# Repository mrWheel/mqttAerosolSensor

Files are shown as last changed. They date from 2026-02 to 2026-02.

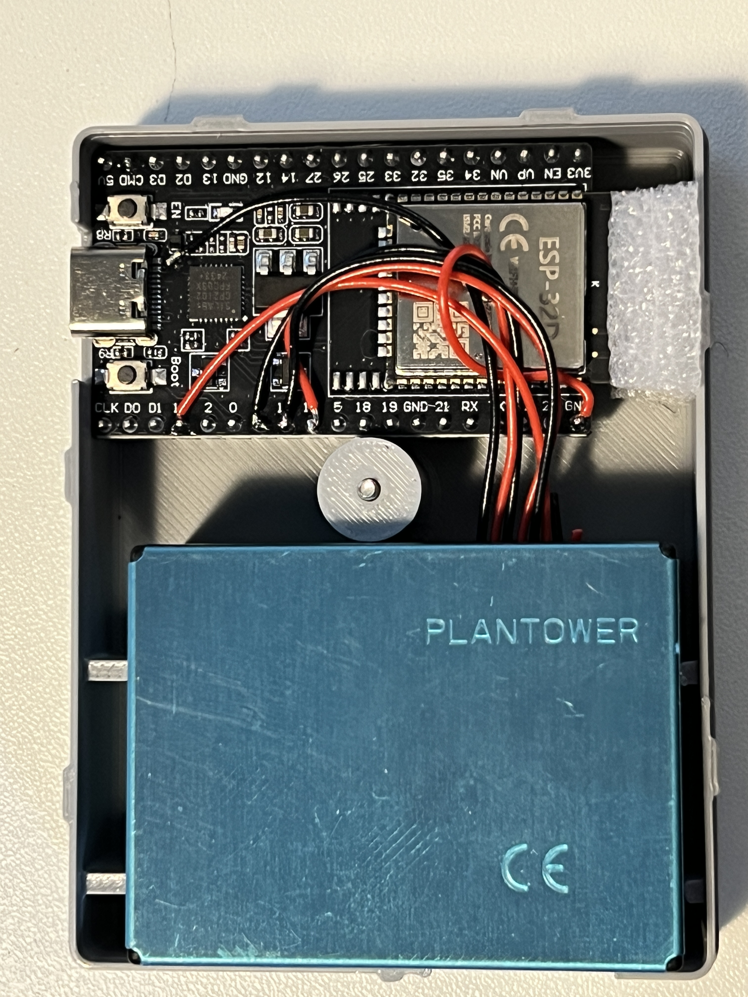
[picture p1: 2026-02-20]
documentation/IMG_9015.JPG

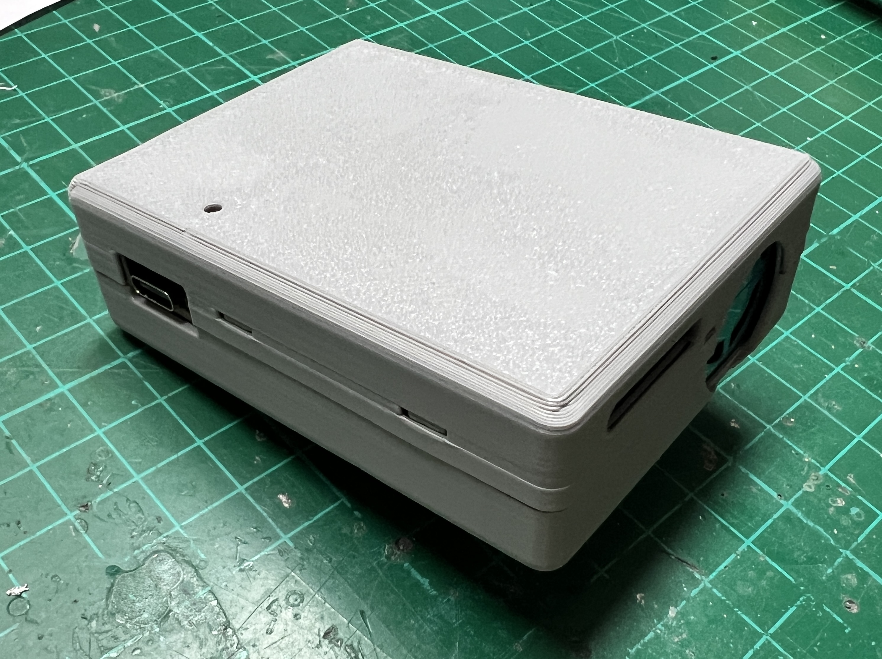
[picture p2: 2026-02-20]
documentation/IMG_9016.jpg

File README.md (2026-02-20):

# luchtSensor

A firmware project for **ESP32 DevKit boards** using **PlatformIO** and the **Arduino framework**.

## Overview

This project manages ESP32 firmware application for a luchtSensor:

### Air Sensor (Luchtsensor)
   - Measures particulate matter using PMSerial sensor
   - Publishes periodic measurements via MQTT
   
Code:
- Use **FreeRTOS** for task management
- Configure WiFi and MQTT via **WiFiManagerExt** captive portal
- Support **JSON** via ArduinoJson
- Feature a button (active within 30s after boot) to clear WiFi credentials
- Implement comprehensive logging via the **Logger** utility

## Architecture

```
┌────────────────────┐
│   MQTT Broker      │
└────────┬───────────┘
         │
         ▼                                        
┌─────────────────────┐  
│   Air Sensor        │  
│  (ESP32-Dev)        │  
│─────────────────────│  
│ WiFiManagerExt      │  
│ MqttClient          │  
│ pms5003AirSensor    |  
|           (PMSerial)│  
│─────────────────────│  
│ Publishes:          │  
│  - luchtsensor/data │  
└─────────────────────┘  
```

## Project Structure

```
luchtSensor/
├── platformio.ini              # PlatformIO configuratie
├── .gitignore                  # Git exclusions
├── DOCUMENTATION.md            # Projectdocumentatie
├── roadmap.md                  # Dit bestand
│
├── include/                    # Gedeelde code
│   ├── pms5003AirSensor.h      # Fijnstofsensor wrapper (PMSerial)
│   ├── logger.h                # Centrale logging utility
│   ├── mqttClient.h            # MQTT client wrapper (PubSubClient)
│   ├── mqttConfig.h            # MQTT configuratie storage
│   └── wifiManagerExt.h        # WiFi/MQTT configuratie manager
│
├── src/                    
│   ├── main.cpp                # Hoofd programma
│   ├── pms5003AirSensor.cpp    # Fijnstofsensor wrapper (PMSerial)
│   ├── logger.cpp              # Centrale logging utility
│   ├── mqttClient.cpp          # MQTT client wrapper (PubSubClient)
│   ├── mqttConfig.cpp          # MQTT configuratie storage
│   └── wifiManagerExt.cpp      # WiFi/MQTT configuratie manager
│
├── documentation/             # Extra documentatie
│   └── mqtt-architecture-diagram.txt
│
├── config_examples/           # Voorbeeld configuraties
│   └── multi_device_mqtt.yaml
│
└── .pio.nosync/              # Build artifacts (niet in git)
```

## Features

### include

#### Logger
Centralized logging utility with:
- Log levels: `INFO`, `WARN`, `ERROR`, `DEBUG`
- Automatic timestamps in milliseconds
- Printf-style formatting
- Consistent output across all modules

```cpp
Logger::info("Device started");
Logger::warn("Low memory");
Logger::error("Sensor read failed");
Logger::debug("Variable x = %d", x);
```

#### WiFiManagerExt
Extended WiFi configuration manager:
- Captive portal for WiFi and MQTT setup
- Stores credentials in LittleFS (`/config.json`)
- **PIN_ERASE_WIFI** monitoring during WiFi connection
- 60-second timeout with automatic restart

#### MqttClient
MQTT client wrapper:
- Simplified publish/subscribe with JSON support
- Automatic reconnection handling
- Built on PubSubClient library

#### Air Sensor
- Measures PM1.0, PM2.5, PM10 concentrations
- Configurable measurement interval (default: 2 minutes)
- Publishes to `pms5003/data` topic
- **PIN_ERASE_WIFI** clears credentials within 20 seconds of boot

## Getting Started

### Prerequisites

- [PlatformIO](https://platformio.org/) installed
- ESP32 DevKit board
- USB cable for programming

### Building

The project uses environment-specific builds. Never build the default environment:

```bash
# Build air sensor firmware
pio run -e mqttAerosolSensor
```

### Uploading

```bash
# Upload air sensor
pio run -e mqttAerosolSensor --target upload
```

### Monitoring

```bash
# Monitor serial output (115200 baud)
pio device monitor -e mqttAerosolSensor
```

## Configuration

### First Boot

On first boot, the device will:
1. if no config.json found ór if there are not allready WiFi-credentiels;
   - Start a WiFi access point (AP mode) 
   - Display AP name on serial output
   - Open configuration portal at `192.168.4.1`

### Configuration Portal

Connect to the device's WiFi AP and navigate to the portal to configure:
- **WiFi SSID and password**
- **MQTT broker host** (IP or hostname)
- **MQTT port** (default: 1883)
- **MQTT topix** (default: pms5003/data)
- **MQTT username** (optional)
- **MQTT password** (optional)

Settings are saved to LittleFS and persist across reboots.

### PIN_ERASE_WIFI

To clear all WiF credentials:
1. Press and release the PIN_ERASE_WIFI button a few times during boot within 30 seconds after boot-start
2. Release button
3. Device will restart in configuration mode

## GPIO Pin Assignments

### Air Sensor

| Pin | Function | Notes |
|-----|---|---|
| GPIO16 | PM Sensor RX | UART receive from sensor |
| GPIO17 | PM Sensor TX | UART transmit to sensor |
| GPIOx | Config Button | Active after 10 seconds pressed |

## MQTT Topics
**Publishes:**
- `pms5003/data` - Measurement data in JSON format

**Example payload:**
```json
{
  "devId": "LS609c3e08",
  "pm1": 7.6,
  "pm25": 8.7,
  "pm10": 12.3,
  "timestamp": 123456
}
```

**Fields:**
- `devId`: Unique device identifier based on MAC address (format: LS + last 8 hex digits of MAC)
- `pm1`: PM1.0 concentration in µg/m³
- `pm25`: PM2.5 concentration in µg/m³
- `pm10`: PM10 concentration in µg/m³
- `timestamp`: Milliseconds since device boot

## FreeRTOS Tasks

| Task | Function |
|---|---|
| taskButtonMonitor | Monitors PIN_ERASE_WIFI |
| taskMqttLoop | Maintains MQTT connection |
| taskMeasurement | Periodic sensor readings |

## Development

### PlatformIO Configuration

The project uses `platformio.ini`:

- **[env]**: Shared configuration
- **[env:mqttAerosolSensor]**: Air sensor specific settings

### Build Flags

Build flags define specific parameters:
- Device identifiers
- GPIO pin assignments
- Timing intervals
- MQTT topics

See `platformio.ini` for complete configuration details.

## Dependencies

### Core Libraries
- **WiFiManager** (^2.0.17) - WiFi configuration portal
- **PubSubClient** - MQTT client
- **ArduinoJson** (^7.0.4) - JSON parsing/serialization
- **FS & LittleFS** - Filesystem for configuration storage

### Device-Specific Libraries
- **PMSerial** (^1.2.0) - Particulate matter sensor (air sensor only)

## Contributing

Toine & Willem

## Support

For issues and questions, please use the GitHub issue tracker.

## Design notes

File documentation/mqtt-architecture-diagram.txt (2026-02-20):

┌────────────────────┐
│    MQTT Broker     │
└────────┬───────────┘
         │
 ┌───────┴────────────────────────────────┐
 │                                        │
 ▼                                        ▼
┌─────────────────-───┐            ┌────────────────────────┐
│   Luchtsensor       │            │   Ventilatorregelaar   │
│   (ESP32-Dev)       │            │   (ESP32-Dev)          │
│─────────────────-───│            │────────────────────────│
│  WiFiManagerExt     │            │  WiFiManagerExt        │
│  MqttClient         │            │  MqttClient            │
│  AirSensor(PMSerial)│            │  StepperMotor          │
│───────────────────-─│            │────────────────────────│
│ Publishes:          │            │ Publishes:             │
│  - luchtsensor/data │            │  - ventilator/status   │
│                     │            │ Subscribes:            │
│                     │            │  - ventilator/command  │
└──────────────────-──┘            └────────────────────────┘

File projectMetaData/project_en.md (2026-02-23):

# mqttAerosolSensor

This project describes a practical ESP32 + PMS5003 fine-dust monitor that publishes PM1.0, PM2.5, and PM10 values via MQTT.

The setup is intentionally simple (ESP32 DevKitC + PMS5003 over UART).

After wiring the sensor to the proper 5V rail, measurements worked reliably. The project then sends data to an MQTT broker for integration with tools like Home Assistant or Grafana, making it easy to visualize trends and trigger automations.

In short, this is a compact maker project that combines straightforward hardware with meaningful real-world insights about indoor air quality.

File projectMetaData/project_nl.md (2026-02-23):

# mqttAerosolSensor

Dit project beschrijft een praktische ESP32 + PMS5003 fijnstofmeter die PM1.0-, PM2.5- en PM10-waarden via MQTT publiceert.

De opzet is bewust eenvoudig gehouden (ESP32 DevKitC + PMS5003 via UART).

Na het aansluiten van de sensor op de juiste 5V-rail werkten de metingen betrouwbaar. Het project verstuurt de data vervolgens naar een MQTT-broker voor integratie met tools zoals Home Assistant of Grafana, zodat trends eenvoudig te visualiseren zijn en automatiseringen kunnen worden getriggerd.

Kortom: dit is een compact makerproject dat eenvoudige hardware combineert met waardevolle, realistische inzichten in de binnenluchtkwaliteit.

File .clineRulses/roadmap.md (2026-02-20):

# 🧠 Projectbeschrijving — luchtSensor

Een firmware project voor **ESP32-dev boards** met **PlatformIO** en **Arduino framework**.

## codingRules

Lees codingRules.md

---

## 🔹 Doel

Code ontwikkeling voor de luchtSensor firmwares ontwikkelen:

**Luchtsensor**
   - Meet fijnstof via **PMSerial**.
   - Publiceert periodiek via **MQTT**.

De code:
- Gebruikt **FreeRTOS**.
- Configureert WiFi en MQTT via **WiFiManagerExt**.
- Ondersteunt **JSON** via **ArduinoJson**.
- Heeft een eraseknop (werkt binnen 30s na opstart) om WiFi-credentials te wissen.
- Loggt uitvoerig met `Serial.printf()` via de **Logger** utility.

---

## 🔹 PlatformIO configuratie

### platformio.ini
```
[platformio]
workspace_dir = .pio.nosync
default_envs = mqttAerosolSensor

[env]
platform = espressif32
board = esp32dev
framework = arduino
monitor_speed = 115200
lib_ldf_mode = deep
lib_archive = false
lib_deps = 
    tzapu/WiFiManager @ ^2.0.17
    knolleary/PubSubClient
    FS
    LittleFS
    bblanchon/ArduinoJson @ ^7.0.4
    https://github.com/fu-hsi/PMS.git

[env:mqttAerosolSensor]
build_flags =
    -DPIN_PM_RX=16
    -DPIN_PM_TX=17
    -DPIN_PM_ENABLE=4
    -DPIN_PM_RESET=13
    -DPIN_ERASE_WIFI=0
    -DPM_NEVER_SLEEPS
    -DTOPIC_DATA="\"luchtsensor/data\""
    -DLOG_LEVEL=LOG_LEVEL_DEBUG
```

Gebruik: `pio run -e mqttAerosolSensor`

---

## 🔹 Mappenstructuur

```
mqttAerosolSensor/
├── platformio.ini              # PlatformIO configuratie
├── .gitignore                  # Git exclusions
├── DOCUMENTATION.md            # Projectdocumentatie
├── roadmap.md                  # Dit bestand
│
├── include/                    # Gedeelde code
│   ├── pms5003AirSensor.h      # Fijnstofsensor wrapper (PMSerial)
│   ├── logger.h                # Centrale logging utility
│   ├── mqttClient.h            # MQTT client wrapper (PubSubClient)
│   ├── mqttConfig.h            # MQTT configuratie storage
│   └── wifiManagerExt.h        # WiFi/MQTT configuratie manager
│
├── src/                    
│   ├── main.cpp                # Hoofd programma
│   ├── pms5003AirSensor.cpp    # Fijnstofsensor wrapper (PMSerial)
│   ├── logger.cpp              # Centrale logging utility
│   ├── mqttClient.cpp          # MQTT client wrapper (PubSubClient)
│   ├── mqttConfig.cpp          # MQTT configuratie storage
│   └── wifiManagerExt.cpp      # WiFi/MQTT configuratie manager
│
├── documentation/             # Extra documentatie
│   └── mqtt-architecture-diagram.txt
│
├── config_examples/           # Voorbeeld configuraties
│   └── multi_device_mqtt.yaml
│
└── .pio.nosync/              # Build artifacts (niet in git)
```

### Directory details

#### luchtsensor/
Device-specifieke code voor de luchtsensor:
- `main.cpp`: Hoofdapplicatie met FreeRTOS taken voor metingen en MQTT

#### include/
Header (.h) files voor herbruikbare modules:

**airSensor.cpp/.h**
- Wrapper voor PMSerial library en PMS sensor hardware
- Meet PM1.0, PM2.5, PM10 concentraties (atmospheric environment µg/m³)
- Gebruikt voor luchtsensor device

**Functionaliteit:**
- `begin()`: Initialiseer UART communicatie en optionele RESET pin
- `reset()`: Hardware reset via PIN_PM_RESET (LOW pulse van 100ms)
- `wakeUp()`: Stuur wakeup commando naar sensor
- `sleep()`: Zet sensor in sleep mode voor stroomverbruik besparing
- `read()`: Lees sensor data met 5 seconden timeout en RTOS-friendly polling
- `pm1()`, `pm25()`, `pm10()`: Haal laatste gemeten waardes op
- `getLastData()`: Verkrijg complete PMS::DATA structuur

**Hardware pins:**
- `PIN_PM_RESET`: Optionele hardware reset pin (default -1, sensor heeft interne pull-up)
- Wanneer gedefinieerd: Configured als OUTPUT, normaal HIGH, reset door LOW pulse
- `PIN_PM_ENABLE`: Hardware enable pin, sensor heeft interne pull-up

**logger.cpp/.h**
- Centrale logging utility (zie volgende sectie)
- Gebruikt door alle modules

**mqttClient.cpp/.h**
- Wrapper voor PubSubClient library
- Vereenvoudigt MQTT publish/subscribe met JSON
- Automatische reconnection handling

**mqttConfig.cpp/.h**
- Storage class voor MQTT instellingen (host, port, user, pass)
- Gebruikt door wifiManagerExt en mqttClient

**telnetServer.cpp/.h**
- Telnet server voor remote console toegang
- Single-connection mode: maximaal 1 actieve client tegelijk
- Automatische disconnectie van oude sessie bij nieuwe connectie
- Gebruikt voor remote debugging en device management

**Functionaliteit:**
- `begin()`: Start telnet server op poort 23
- `stop()`: Stop server en disconnect alle clients
- `loop()`: Hoofdloop voor client handling (roep aan in RTOS task)
- `hasClient()`: Check of client verbonden is
- `print()`, `println()`, `printf()`: Output naar telnet client
- `setCommandCallback()`: Registreer custom command handler

**Single-Connection Gedrag:**
- Bij nieuwe connectie wordt oude client automatisch gedisconnect
- Oude client ontvangt notificatie voordat sessie wordt gesloten
- "Last connection wins" principe: nieuwste client krijgt altijd toegang
- Oude sessie krijgt bericht:
  ```
  ===================================
    New connection detected!
    Your session will be closed.
  ===================================
  ```

**Built-in Commands:**
- `help`: Toon beschikbare commando's
- `status`: Toon device status (uptime, memory, WiFi RSSI)
- `clear`: Clear screen (VT100 escape codes)
- Custom commands via callback functie

**Integratie met Logger:**
- Logger output kan naar telnet client worden gestuurd
- `Logger::setTelnetServer(&telnetServer)` voor telnet logging
- Logs worden naar zowel Serial als Telnet gestuurd

**mDNS Service:**
- Geadverteerd als `_telnet._tcp` op poort 23
- Toegankelijk via: `telnet sensor-XXXX.local`

**wifiManagerExt.cpp/.h**
- Uitbreiding op WiFiManager library
- Configuratie portal met MQTT velden
- Opslag van credentials in LittleFS (/config.json)
- Reset button monitoring tijdens WiFi connectie
- 60 seconden timeout met automatische restart
- **MAC-gebaseerde identificatie en mDNS**

**MAC Address Identificatie:**
- Leest ESP32 base MAC address via `esp_read_mac()`
- Genereert twee formats:
  - Volledig: Laatste 4 bytes (8 hex karakters) voor MQTT Client ID
  - Kort: Laatste 2 bytes (4 hex karakters) voor WiFi AP en mDNS namen

**WiFi Access Point namen:**
- Luchtsensor: `sensor-XXXX` (bijv. "sensor-3c4d")

**MQTT Client IDs:**
- Luchtsensor: `LS` + volledig MAC suffix (bijv. "LS1a2b3c4d")
- Toegankelijk via `wifiManager.getClientId()`

**mDNS (Multicast DNS):**
- Automatisch gestart na succesvolle WiFi verbinding
- Hostname format: `<device>-<kort_mac>.local`
- Luchtsensor: `sensor-XXXX.local` (bijv. "sensor-3c4d.local")
- Geadverteerde services:
  - HTTP op poort 80 (`_http._tcp`)
  - Telnet op poort 23 (`_telnet._tcp`)
- Gebruik: `ping sensor-3c4d.local`

**Functies:**
- `initMacAddress()`: Initialiseer MAC address en genereer IDs
- `startMDNS()`: Start mDNS service met hostname
- `getMacSuffix()`: Verkrijg volledig MAC suffix
- `getClientId()`: Verkrijg MQTT client ID

#### documentation/
Extra projectdocumentatie en diagrammen

#### config_examples/
Voorbeeld configuraties voor diverse setups

---

## 🔹 Centrale logging (logger.*)

### Overzicht

De `Logger` utility biedt een centrale, gestructureerde manier om log messages te schrijven naar de seriële poort. Alle modules in het project gebruiken dezelfde logging interface voor consistente output.

### Kenmerken

**Log levels:**
- `INFO`: Normale operationele berichten (altijd zichtbaar)
- `WARN`: Waarschuwingen die aandacht vereisen
- `ERROR`: Foutmeldingen
- `DEBUG`: Gedetailleerde debug informatie (kan uit worden gezet)

**Timestamp formatting:**
- Automatische timestamps in formaat: `[12345]` (milliseconden sinds boot)
- Helpt bij timing analysis en debugging

**Type indicators:**
- `[INFO]`, `[WARN]`, `[ERROR]`, `[DEBUG]` prefixes
- Makkelijk te filteren in serial output

**Printf-style formatting:**
- Ondersteunt variabelen met format specifiers
- Bijvoorbeeld: `Logger::info("Speed: %.1f", speed);`

### Gebruik

**Include in je code:**
```cpp
#include "logger.h"
```

**Basis logging:**
```cpp
Logger::info("Device started");
Logger::warn("Low memory");
Logger::error("Sensor read failed");
Logger::debug("Variable x = %d", x);
```

**Met variabelen:**
```cpp
float temperature = 23.5;
int count = 42;
Logger::info("Temperature: %.1f°C, Count: %d", temperature, count);
```

**String variabelen:**
```cpp
const char* status = "connected";
Logger::info("MQTT status: %s", status);
```

### Output voorbeeld

```
[  1234] [INFO] Booting Ventilatorregelaar...
[  1567] [INFO] taskButtonMonitor started, initial PIN_ERASE_WIFI state: HIGH
[  1589] [INFO] Loaded MQTT config from file:
[  1590] [INFO]   Host: 'mqtt.local'
[  1591] [INFO]   Port: '1883'
[  2345] [INFO] Starting WiFi connection attempt (60 second timeout)...
[  8901] [INFO] MQTT connection details:
[  8902] [INFO]   clientId: ventilator
[  8903] [INFO]   host: mqtt.local
[  8904] [INFO]   user: esp32
[  9234] [INFO] MQTT connected
[ 10123] [INFO] Ventilatorregelaar device started with RTOS tasks
```

### Implementatie details

De Logger is geïmplementeerd als statische class met:
- `logger.h`: Header met public interface
- `logger.cpp`: Implementatie met `Serial.printf()` calls

Alle log functies gebruiken `Serial.printf()` voor geformatteerde output naar baudrate 115200.

### Best practices

1. **Gebruik juiste log level:**
   - `info()`: Normale flow events (startup, config geladen, connected)
   - `warn()`: Potentiële problemen (retry, timeout warning)
   - `error()`: Echte fouten (sensor fail, connection lost)
   - `debug()`: Tijdelijke debug info (alleen tijdens ontwikkeling)

2. **Wees duidelijk:**
   - Gebruik beschrijvende messages
   - Include relevante variabele waardes
   - Vermijd te veel logging in tight loops

3. **Format strings:**
   - `%d` voor integers
   - `%f` of `%.1f` voor floats (met precisie)
   - `%s` voor strings
   - `%x` voor hexadecimale waardes

4. **State changes loggen:**
   - Pin state changes
   - Connection status changes
   - Mode transitions
   - Configuration changes

---

## 🔹 Devicebeschrijving

### 🌫️ Luchtsensor

De luchtsensor device meet fijnstof concentraties met een PMS5003 sensor via de PMSerial library.

#### Hardware configuratie
- **PMS5003 sensor**: Particulate matter sensor
  - `PIN_PM_RX` (GPIO16): UART receive pin
  - `PIN_PM_TX` (GPIO17): UART transmit pin
  - `PIN_PM_ENABLE`: Power control pin voor sensor aan/uit schakelen
  - `PIN_PM_RESET`: Hardware reset pin (optioneel, default -1)

#### Sensor modes

**PM_NEVER_SLEEPS mode** (build flag):
- Sensor blijft continu ingeschakeld
- Geen warmup tijd nodig tussen metingen
- Measurement interval direct uit config.json gebruikt
- Hogere stroomverbruik maar snellere metingen mogelijk

**Normal mode** (zonder PM_NEVER_SLEEPS):
- Sensor wordt uitgeschakeld tussen metingen voor stroomverbruik optimalisatie
- Minimum interval: 30 seconden (waarvan 30s warmup)
- Sensor reset + enable + wakeUp voor elke meting
- Lagere stroomverbruik maar langere minimum interval

#### Sensor reset sequentie

Bij opstarten en tussen metingen (normal mode):
1. `airSensor.reset()` - Hardware reset via PIN_PM_RESET (indien gedefinieerd)
2. `digitalWrite(PIN_PM_ENABLE, HIGH)` - Schakel sensor power in
3. `vTaskDelay(2000ms)` - Wacht op power stabilisatie
4. `airSensor.wakeUp()` - Stuur wakeup commando naar sensor
5. `vTaskDelay(30000ms)` - Warmup tijd voor stabiele metingen

#### Zero reading detection

Automatische detectie en recovery van sensor malfuncties:
- Detecteert wanneer PM2.5 EN PM10 beide 0.0 zijn
- Telt consecutive zero readings
- **Bij meer dan 2 opeenvolgende nul-metingen:**
  1. Log waarschuwing
  2. Voer sensor reset uit
  3. WakeUp sensor
  4. Wacht 30 seconden warmup
  5. Reset counter en hervat metingen
- Counter wordt gereset bij elke geldige non-zero meting

#### MQTT publicatie

Publiceert naar `luchtsensor/data` met JSON payload:
```json
{
  "pm25": 12.5,
  "pm10": 15.3,
  "timestamp": 123456789
}
```

#### Measurement statistieken

Tracking in taskMeasurement:
- `framesOk`: Aantal succesvolle metingen
- `framesError`: Aantal gefaalde metingen
- `consecutiveZeroReadings`: Teller voor nul-metingen
- Heartbeat logging elke 60 seconden
- Stats logging elke 30 seconden

#### Reset functionaliteit

- Resetknop binnen 60s na opstart → wissen WiFi/MQTT + herstart
- GPIO0 (PIN_ERASE_WIFI) moet LOW zijn tijdens boot window

#### Telnet interface

Telnet server op port 23 met commands:
- `measure`: Voer directe sensor meting uit en toon resultaat
- Telnet output via Logger wordt naar alle verbonden clients gestuurd

---

## 🔹 RTOS taken

### Luchtsensor taken

| Taak | Functie | Core | Prioriteit |
|---|---|---|---|
| taskButtonMonitor | Detecteert resetknop binnen 60s boot window | 0 | 2 |
| taskMqttLoop | Houdt MQTT verbinding levend, automatische reconnect | 0 | 1 |
| taskMeasurement | Sensor metingen, zero detection, MQTT publish | 1 | 4 |
| taskTelnetServer | Telnet server loop voor remote debugging | 0 | 1 |

---

## 🔹 GPIO-overzicht (ESP32 DevKit)

| Pin | Functie | Opmerking |
|---|---|---|
| EN | Hardware reset | Niet gebruiken |
| GPIO0 | Bootloader | Niet gebruiken |
| GPIO0 | Erase WiFi | Aanbevolen |
| GPIO16/17 | PM RX/TX | Fijnstofsensor |
| GPIOxx | PM Reset | Fijnstofsensor |
| GPIOxx | PM Enable | Fijnstofsensor |

---

## 🔹 MQTT topics

| Device | Publishes | Subscribes |
|---|---|---|
| Luchtsensor | luchtsensor/data | — |

---

## 🔹 ASCII Architectuurdiagram

```
┌────────────────────┐
│   MQTT Broker      │
└────────┬───────────┘
         │
 ┌───────┴────────────────────────────────┐
 │                                        │
 ▼                                        ▼
┌───────────────-─────┐           ┌────────────────────────┐
│   Luchtsensor       │           │   Ventilatorregelaar   │
│  (ESP32-Dev)        │           │  (ESP32-Dev)           │
│────────────────-────│           │────────────────────────│
│ WiFiManagerExt      │           │ WiFiManagerExt         │
│ MqttClient          │           │ MqttClient             │
│ AirSensor (PMSerial)│           │ StepperMotor           │
│─────────────────-───│           │────────────────────────│
│ Publishes:          │           │ Publishes:             │
│  - luchtsensor/data │           │  - ventilator/status   │
│                     │           │ Subscribes:            │
│                     │           │  - ventilator/command  │
└──────────────────-──┘           └────────────────────────┘
```

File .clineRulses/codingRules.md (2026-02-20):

# codingRules

**Code Style:**
   - Use **Allman** (BSD) style for all code blocks
   - Use **lowerCamelCase** for function and variable names
   - Use **Object Calisthenics** (zie: https://williamdurand.fr/2013/06/03/object-calisthenics/)
   - Use <Serial>.printf() and snprintf()
   - Use std::string and not String
   - Prefix all comments with `//--`
   - Place comments above the code block they describe (if more then 10 lines or so)
   - Indent two (2) spaces
   - Never remove empty lines or skip code sections

Use the Code Style for .cpp, .c, .h,  .js, .php, .css files

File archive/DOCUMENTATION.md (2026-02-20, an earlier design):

# Multi-Device MQTT Project (ESP32, RTOS)

- Meerdere devices (luchtsensor + ventilatorregelaar)
- Gedeelde WiFi/MQTT configuratie via WifiManagerExt + MqttClient
- Allman style, lowerCamelCase, Object Calisthenics-achtig opgezet
- Indent 2 positions
- FreeRTOS taken per device
- Pins en topics via build_flags

Zie `documentation/mqtt-architecture-diagram.txt` voor een ASCII overzicht.

Logging: zie shared/logger.* voor centraal gebruik van Serial.printf().

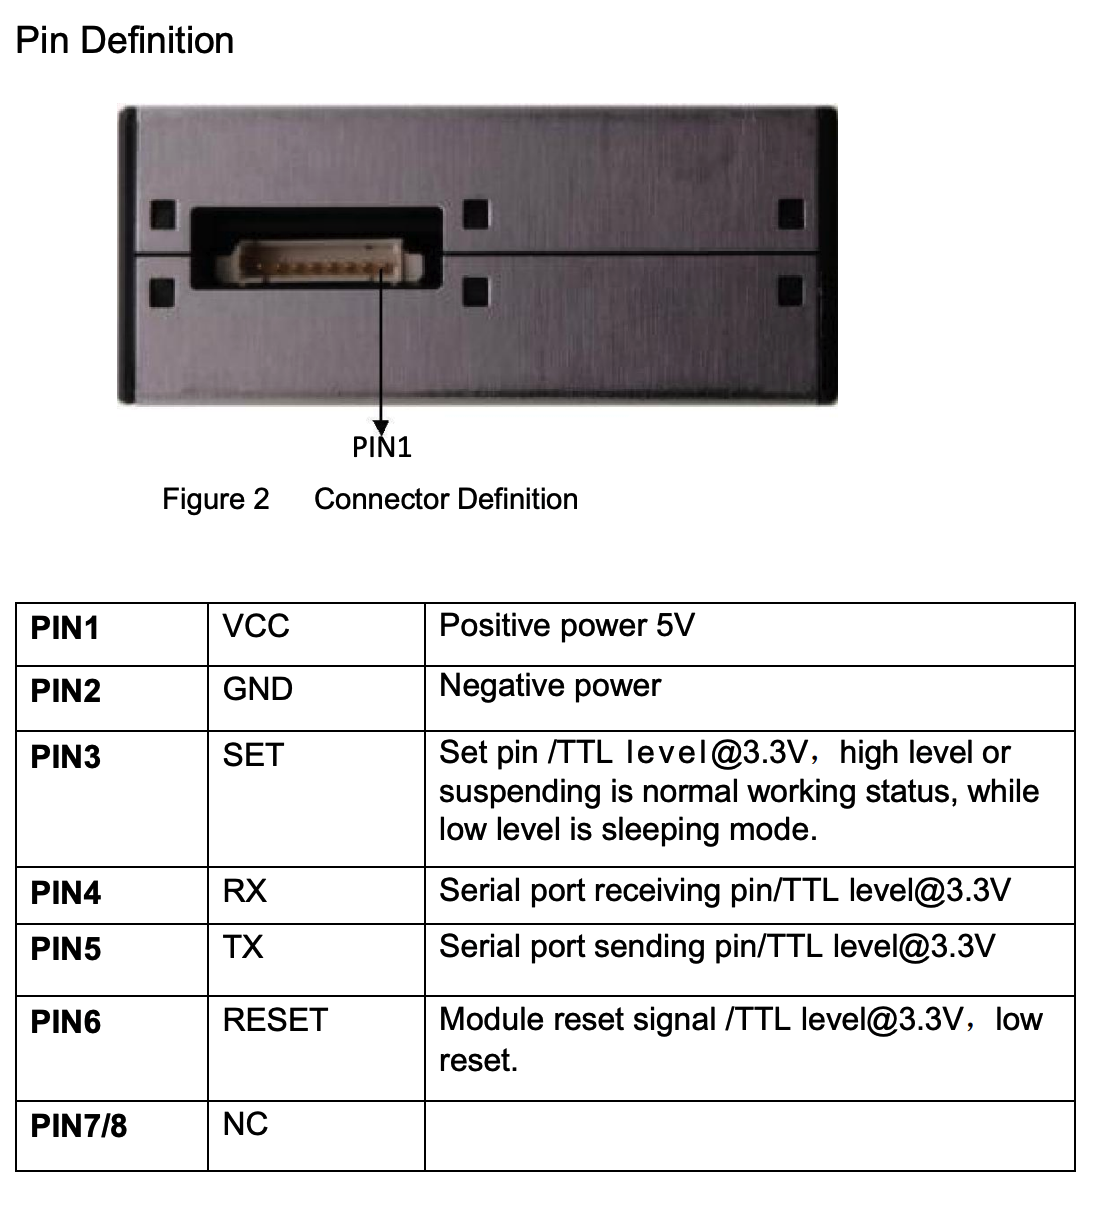
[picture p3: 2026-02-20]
documentation/PMS5003-pins.png

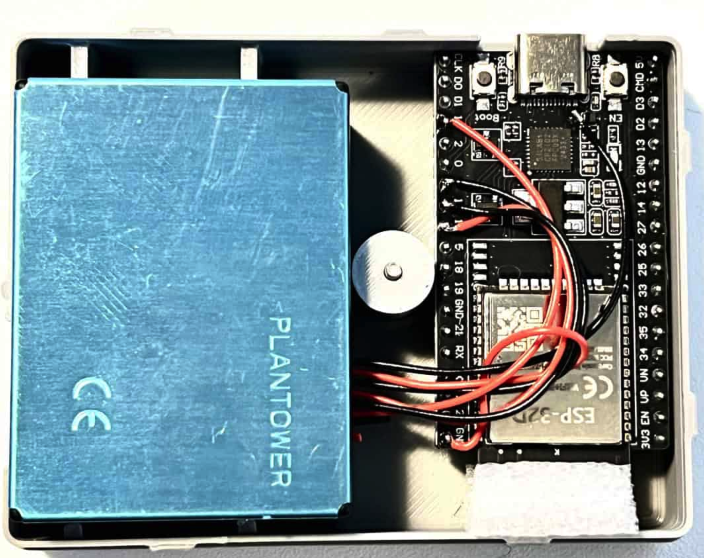
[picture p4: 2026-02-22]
projectMetaData/mqttAerosolSensor.png

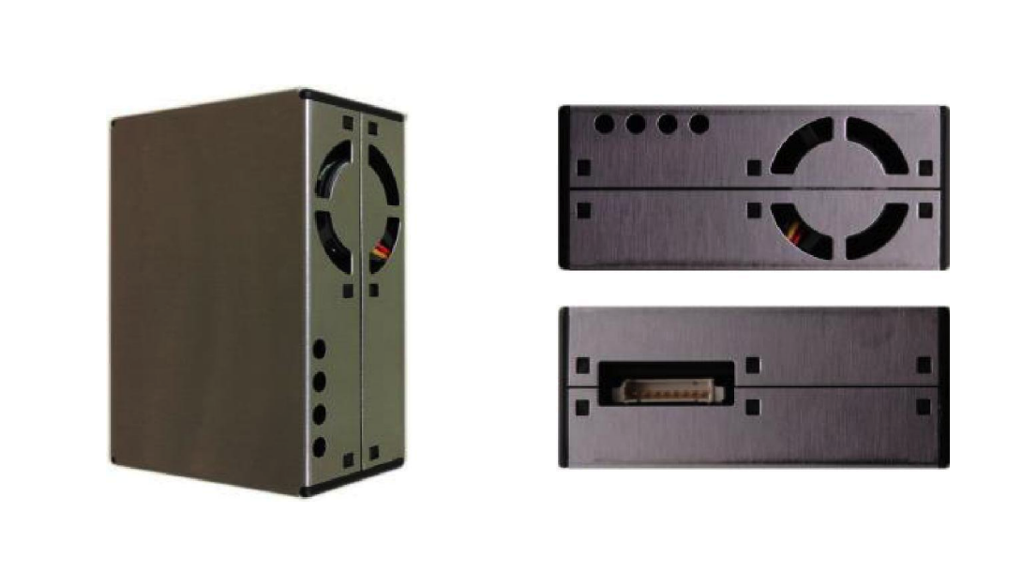
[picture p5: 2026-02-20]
documentation/PMS5003-a.png

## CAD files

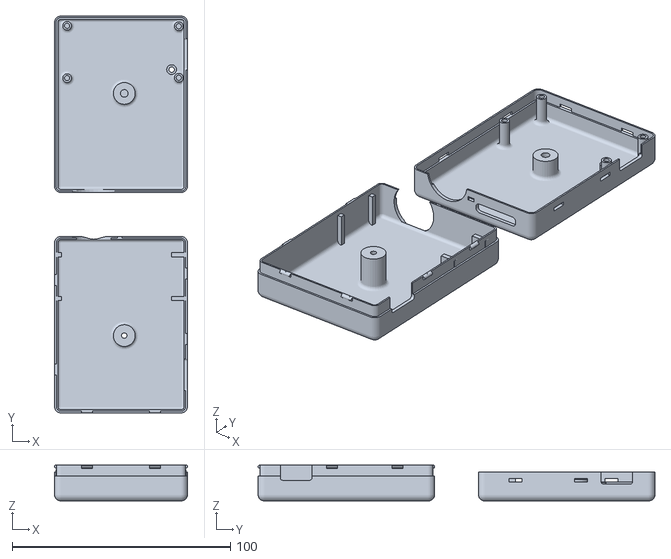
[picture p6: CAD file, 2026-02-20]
3Dfiles/mqttAerosolSensor.stl
61.0 x 182.0 x 16.5

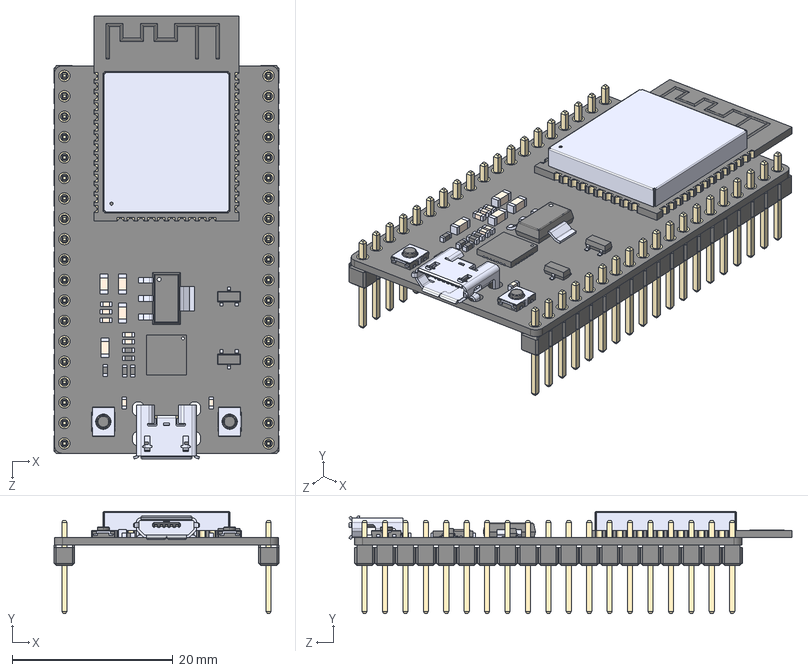
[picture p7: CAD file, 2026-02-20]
documentation/ESP32-DEVKITC-32E/ESP32-DEVKITC-32E.step
27.9 x 12.7 x 55.1 mm
board
header x 2
ESP32-WROOM-32D
micro usb
button x 2
CP2102N-A01-GQFN28
AMS1117-3.3
SS8050-G
components^DEVKIT V1 ESP32-WROOM-32

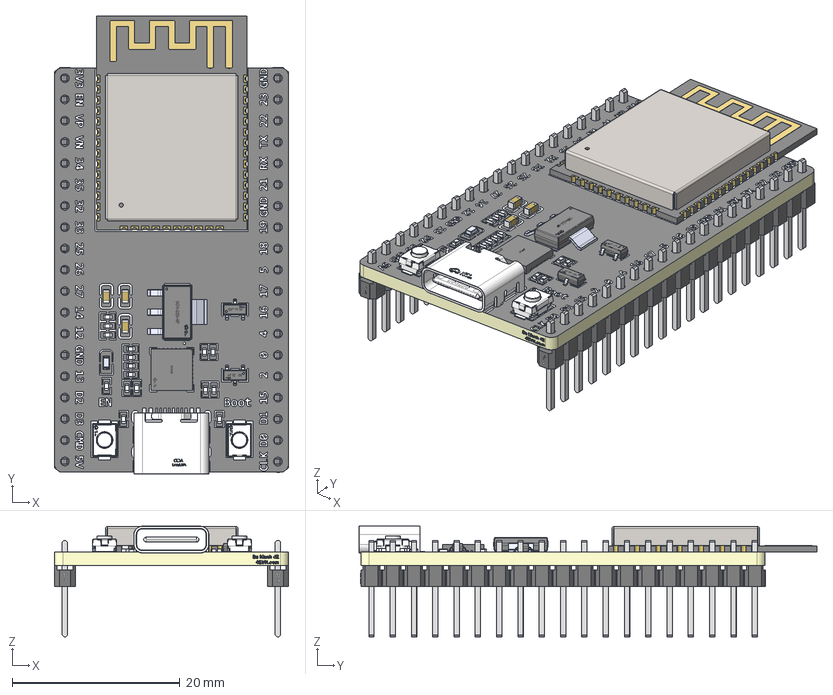
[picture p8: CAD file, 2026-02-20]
3Dfiles/ESP32-DevkitC32D.step
27.9 x 54.6 x 13.2 mm
Board~QTmk
TopSilkscreen~QTmk
BottomSilkscreen~QTmk
USB-C_SMD-TYPE-C-31-M-12~USB-C_SMD-TYPE-C-31-M-12~QTmk
C0603~C0603_L1.6-W0.8-H0.8~QTmk x 3
R0402~R0402_L1.0-W0.5-H0.4~QTmk x 16
SOT-223-3_L6.5-W3.4-P2.30-LS7.0-BR~SOT-223-4P_L6.5-W3.5-H1.6-LS7.0-P2. 30~QTmk
SW-SMD_L3.9-W3.0-P4.45~SW-SMD_L3.9-W2.9-H2.0-LS4.8~QTmk x 2
LED0603-RD_RED~LED0603-RD_RED~QTmk
HDR-TH_19P-P2.54-V-M~HDR-TH_19P-P2.54-M-LI-1X19P~QTmk x 2
SOT-23-3_L2.9-W1.3-P1.90-LS2.4-BR~SOT-23-3P_L2.9-W1.3-H1.0-LS2.4-P0.9 5~QTmk x 2
QFN-28_L5.0-W5.0-P0.50-TL-EP3.3~QFN-28_L5.0-W5.0-H0.9-P0.50~QTmk
ESP32_5x5_20210301.STEP^ESP32_5x5_20210301.STEP_Submodel-SLP48_5X5_pa rt_DesignRootModel_PCB_ESP32-WROOM-32E_V1(2)_PCB_ESP32-WROOM-32E_V1.ST EP
trace_1^Submodel-ANT_L_TYPEA_1501846164_part_DesignRootModel_PCB_ESP3 2-WROOM-32E_V1(2)_PCB_ESP32-WROOM-32E_V1.STEP
DFN1006.STEP^DFN1006.STEP_Submodel-SOD882_part_DesignRootModel_PCB_ES P32-WROOM-32E_V1(2)_PCB_ESP32-WROOM-32E_V1.STEP
R0201_20210301.STEP^R0201_20210301.STEP_Submodel-R0201_part_DesignRoo tModel_PCB_ESP32-WROOM-32E_V1(2)_PCB_ESP32-WROOM-32E_V1.STEP x 3
L0201_20210301.STEP^L0201_20210301.STEP_Submodel-L0201_part_DesignRoo tModel_PCB_ESP32-WROOM-32E_V1(2)_PCB_ESP32-WROOM-32E_V1.STEP x 2
C0201_20210301.STEP^C0201_20210301.STEP_Submodel-C0201_part_DesignRoo tModel_PCB_ESP32-WROOM-32E_V1(2)_PCB_ESP32-WROOM-32E_V1.STEP x 17
SOIC8_208_20210301.STEP^SOIC8_208_20210301.STEP_Submodel-SOIC08-WN_pa rt_DesignRootModel_PCB_ESP32-WROOM-32E_V1(2)_PCB_ESP32-WROOM-32E_V1.ST EP
XTAL3225_20210301.STEP^XTAL3225_20210301.STEP_Submodel-3225_part_Desi gnRootModel_PCB_ESP32-WROOM-32E_V1(2)_PCB_ESP32-WROOM-32E_V1.STEP
C0402_20210301.STEP^C0402_20210301.STEP_Submodel-0402A_part_DesignRoo tModel_PCB_ESP32-WROOM-32E_V1(2)_PCB_ESP32-WROOM-32E_V1.STEP x 2
uid__1-339^DesignRootModel_PCB_ESP32-WROOM-32E_V1(2)_PCB_ESP32-WROOM- 32E_V1.STEP
uid__1-346^DesignRootModel_PCB_ESP32-WROOM-32E_V1(2)_PCB_ESP32-WROOM- 32E_V1.STEP
uid__1-347^DesignRootModel_PCB_ESP32-WROOM-32E_V1(2)_PCB_ESP32-WROOM- 32E_V1.STEP
uid__1-354^DesignRootModel_PCB_ESP32-WROOM-32E_V1(2)_PCB_ESP32-WROOM- 32E_V1.STEP
uid__1-364^DesignRootModel_PCB_ESP32-WROOM-32E_V1(2)_PCB_ESP32-WROOM- 32E_V1.STEP
uid__1-371^DesignRootModel_PCB_ESP32-WROOM-32E_V1(2)_PCB_ESP32-WROOM- 32E_V1.STEP
uid__1-376^DesignRootModel_PCB_ESP32-WROOM-32E_V1(2)_PCB_ESP32-WROOM- 32E_V1.STEP
uid__1-377^DesignRootModel_PCB_ESP32-WROOM-32E_V1(2)_PCB_ESP32-WROOM- 32E_V1.STEP
uid__1-385^DesignRootModel_PCB_ESP32-WROOM-32E_V1(2)_PCB_ESP32-WROOM- 32E_V1.STEP
uid__1-389^DesignRootModel_PCB_ESP32-WROOM-32E_V1(2)_PCB_ESP32-WROOM- 32E_V1.STEP
uid__1-400^DesignRootModel_PCB_ESP32-WROOM-32E_V1(2)_PCB_ESP32-WROOM- 32E_V1.STEP
uid__1-401^DesignRootModel_PCB_ESP32-WROOM-32E_V1(2)_PCB_ESP32-WROOM- 32E_V1.STEP
uid__1-409^DesignRootModel_PCB_ESP32-WROOM-32E_V1(2)_PCB_ESP32-WROOM- 32E_V1.STEP
uid__1-410^DesignRootModel_PCB_ESP32-WROOM-32E_V1(2)_PCB_ESP32-WROOM- 32E_V1.STEP
uid__1-411^DesignRootModel_PCB_ESP32-WROOM-32E_V1(2)_PCB_ESP32-WROOM- 32E_V1.STEP
uid__1-412^DesignRootModel_PCB_ESP32-WROOM-32E_V1(2)_PCB_ESP32-WROOM- 32E_V1.STEP
uid__1-420^DesignRootModel_PCB_ESP32-WROOM-32E_V1(2)_PCB_ESP32-WROOM- 32E_V1.STEP
uid__1-421^DesignRootModel_PCB_ESP32-WROOM-32E_V1(2)_PCB_ESP32-WROOM- 32E_V1.STEP
uid__1-425^DesignRootModel_PCB_ESP32-WROOM-32E_V1(2)_PCB_ESP32-WROOM- 32E_V1.STEP
uid__1-427^DesignRootModel_PCB_ESP32-WROOM-32E_V1(2)_PCB_ESP32-WROOM- 32E_V1.STEP
uid__1-431^DesignRootModel_PCB_ESP32-WROOM-32E_V1(2)_PCB_ESP32-WROOM- 32E_V1.STEP
uid__1-435^DesignRootModel_PCB_ESP32-WROOM-32E_V1(2)_PCB_ESP32-WROOM- 32E_V1.STEP
uid__1-436^DesignRootModel_PCB_ESP32-WROOM-32E_V1(2)_PCB_ESP32-WROOM- 32E_V1.STEP
uid__1-437^DesignRootModel_PCB_ESP32-WROOM-32E_V1(2)_PCB_ESP32-WROOM- 32E_V1.STEP
uid__1-440^DesignRootModel_PCB_ESP32-WROOM-32E_V1(2)_PCB_ESP32-WROOM- 32E_V1.STEP
uid__1-441^DesignRootModel_PCB_ESP32-WROOM-32E_V1(2)_PCB_ESP32-WROOM- 32E_V1.STEP
uid__1-445^DesignRootModel_PCB_ESP32-WROOM-32E_V1(2)_PCB_ESP32-WROOM- 32E_V1.STEP
uid__1-446^DesignRootModel_PCB_ESP32-WROOM-32E_V1(2)_PCB_ESP32-WROOM- 32E_V1.STEP
uid__1-450^DesignRootModel_PCB_ESP32-WROOM-32E_V1(2)_PCB_ESP32-WROOM- 32E_V1.STEP
uid__1-454^DesignRootModel_PCB_ESP32-WROOM-32E_V1(2)_PCB_ESP32-WROOM- 32E_V1.STEP
uid__1-460^DesignRootModel_PCB_ESP32-WROOM-32E_V1(2)_PCB_ESP32-WROOM- 32E_V1.STEP
uid__1-461^DesignRootModel_PCB_ESP32-WROOM-32E_V1(2)_PCB_ESP32-WROOM- 32E_V1.STEP
uid__1-477^DesignRootModel_PCB_ESP32-WROOM-32E_V1(2)_PCB_ESP32-WROOM- 32E_V1.STEP
uid__1-478^DesignRootModel_PCB_ESP32-WROOM-32E_V1(2)_PCB_ESP32-WROOM- 32E_V1.STEP
uid__1-479^DesignRootModel_PCB_ESP32-WROOM-32E_V1(2)_PCB_ESP32-WROOM- 32E_V1.STEP
uid__1-480^DesignRootModel_PCB_ESP32-WROOM-32E_V1(2)_PCB_ESP32-WROOM- 32E_V1.STEP
uid__1-481^DesignRootModel_PCB_ESP32-WROOM-32E_V1(2)_PCB_ESP32-WROOM- 32E_V1.STEP
uid__1-482^DesignRootModel_PCB_ESP32-WROOM-32E_V1(2)_PCB_ESP32-WROOM- 32E_V1.STEP
uid__1-483^DesignRootModel_PCB_ESP32-WROOM-32E_V1(2)_PCB_ESP32-WROOM- 32E_V1.STEP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

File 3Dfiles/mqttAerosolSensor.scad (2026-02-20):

//-----------------------------------------------------------------------
//
//  This is a box for the luchtSensor
//
//  Version 1.0 (2025-12-30)
//
// This design is parameterized based on the size of a PCB.
//
// For many/complex cutoutGrills, you might need to adjust
//  the max number of elements in OpenSCAD:
//
//      Preferences->Advanced->Turn off rendering at 250000 elements
//                                                   ^^^^^^
//
//-----------------------------------------------------------------------

include <./YAPPgenerator_v3.0.2.scad>


myPcb = "ESP32-DevkitC32D.stl";

if (false)
{
  translate([57.5, 2.5 , 9]) 
  {
    rotate([0,0,90]) color("gray") import(myPcb);
  }
}

//---------------------------------------------------------
// This design is parameterized based on the size of a PCB.
//---------------------------------------------------------
// Note: length/lengte refers to X axis, 
//       width/breedte refers to Y axis,
//       height/hoogte refers to Z axis

/*
      padding-back|<------pcb length --->|<padding-front
                            RIGHT
        0    X-axis ---> 
        +----------------------------------------+   ---
        |                                        |    ^
        |                                        |   padding-right 
      Y |                                        |    v
      | |    -5,y +----------------------+       |   ---              
 B    a |         | 0,y              x,y |       |     ^              F
 A    x |         |                      |       |     |              R
 C    i |         |                      |       |     | pcb width    O
 K    s |         |                      |       |     |              N
        |         | 0,0              x,0 |       |     v              T
      ^ |    -5,0 +----------------------+       |   ---
      | |                                        |    padding-left
      0 +----------------------------------------+   ---
        0    X-as --->
                          LEFT
*/


//-- which part(s) do you want to print?
printBaseShell        = true;
printLidShell         = true;
printSwitchExtenders  = false;
printDisplayClips     = false;

// ********************************************************************
// The Following will be used as the first element in the pbc array

//Defined here so you can define the "Main" PCB using these if wanted
pcbLength           = 56;   //-- front to back (X axis)
pcbWidth            = 28.0; //-- side to side (Y axis)
pcbThickness        =  1.7; 
standoffHeight      =  9; //-- How much the PCB needs to be raised from the base to leave room for solderings and whatnot
standoffDiameter    =  4;
standoffPinDiameter =  2.0;
standoffHoleSlack   =  0.4;



//===================================================================
// *** PCBs ***
// Printed Circuit Boards
//-------------------------------------------------------------------
//  Default origin =  yappCoordPCB : yappCoordBoxInside[0,0,0]
//
//  Parameters:
//   Required:
//    p(0) = name
//    p(1) = length
//    p(2) = width
//    p(3) = posx
//    p(4) = posy
//    p(5) = Thickness
//    p(6) = standoff_Height
//    p(7) = standoff_Diameter
//    p(8) = standoff_PinDiameter
//   Optional:
//    p(9) = standoff_HoleSlack (default to 0.4)

//The following can be used to get PCB values elsewhere in the script - not in pcb definition. 
//If "PCB Name" is omitted then "Main" is used
//  pcbLength           --> pcbLength("PCB Name")
//  pcbWidth            --> pcbWidth("PCB Name")
//  pcbThickness        --> pcbThickness("PCB Name") 
//  standoffHeight      --> standoffHeight("PCB Name") 
//  standoffDiameter    --> standoffDiameter("PCB Name") 
//  standoffPinDiameter --> standoffPinDiameter("PCB Name") 
//  standoffHoleSlack   --> standoffHoleSlack("PCB Name") 

pcb = 
[
  // Default Main PCB - DO NOT REMOVE the "Main" line.
    ["Main",       pcbLength, pcbWidth, 0, 0, pcbThickness, standoffHeight, standoffDiameter, standoffPinDiameter, standoffHoleSlack]
   ,["PMS5003",     50, 38, 0, 38, 21.5, 0, 0, 0, 0.4]
];

//-------------------------------------------------------------------                            
//-- padding between pcb and inside wall
paddingFront        = 1;
paddingBack         = 1;
paddingRight        = 1;
paddingLeft         = 1;

//-- Edit these parameters for your own box dimensions
wallThickness       = 1.5;
basePlaneThickness  = 1.5;
lidPlaneThickness   = 1.5;

//-- Total height of box = lidPlaneThickness 
//                       + lidWallHeight 
//--                     + baseWallHeight 
//                       + basePlaneThickness
//-- space between pcb and lidPlane :=
//--      (bottonWallHeight+lidWallHeight) - (standoffHeight+pcbThickness)
baseWallHeight      = 15.0;
lidWallHeight       =  7.3;

//-- ridge where base and lid off box can overlap
//-- Make sure this isn't less than lidWallHeight
ridgeHeight         = 5.0;
ridgeSlack          = 0.2;
roundRadius         = 3.0;

// Box Types are 0-4 with 0 as the default
// 0 = All edges rounded with radius (roundRadius) above
// 1 = All edges sqrtuare
// 2 = All edges chamfered by (roundRadius) above 
// 3 = Square top and bottom edges (the ones that touch the build plate) and rounded vertical edges
// 4 = Square top and bottom edges (the ones that touch the build plate) and chamfered vertical edges
// 5 = Chanfered top and bottom edges (the ones that touch the build plate) and rounded vertical edges
boxType             = 0; // Default type 0

// Set the layer height of your printer
printerLayerHeight  = 0.2;


//---------------------------
//--     C O N T R O L     --
//---------------------------
// -- Render --
renderQuality             = 8;          //-> from 1 to 32, Default = 8

// --Preview --
previewQuality            = 3;          //-> from 1 to 32, Default = 5
showSideBySide            = true;       //-> Default = true
onLidGap                  = 0;  // tip don't override to animate the lid opening
colorLid                  = "YellowGreen";   
alphaLid                  = 1.0;
colorBase                 = "BurlyWood";
alphaBase                 = 1.0;
hideLidWalls              = true;      //-> Remove the walls from the lid : only if preview and showSideBySide=true 
hideBaseWalls             = false;      //-> Remove the walls from the base : only if preview and showSideBySide=true  
showOrientation           = true;       //-> Show the Front/Back/Left/Right labels : only in preview
showPCB                   = false;      //-> Show the switches (for pushbuttons) : only in preview 
showButtonsDepressed      = false;      //-> Should the buttons in the Lid On view be in the pressed position
showOriginCoordBox        = false;      //-> Shows red bars representing the origin for yappCoordBox : only in preview 
showOriginCoordBoxInside  = false;      //-> Shows blue bars representing the origin for yappCoordBoxInside : only in preview 
showOriginCoordPCB        = false;      //-> Shows blue bars representing the origin for yappCoordBoxInside : only in preview 
showMarkersPCB            = false;      //-> Shows black bars corners of the PCB : only in preview 
showMarkersCenter         = false;      //-> Shows magenta bars along the centers of all faces  
inspectX                  = 0;          //-> 0=none (>0 from Back)
inspectY                  = 0;          //-> 0=none (>0 from Right)
inspectZ                  = 0;          //-> 0=none (>0 from Bottom)
inspectXfromBack          = false;       //-> View from the inspection cut foreward
inspectYfromLeft          = true;       //-> View from the inspection cut to the right
inspectZfromBottom        = true;       //-> View from the inspection cut up
printMessages             = true;       //-> Print messages during generation
//---------------------------
//--     C O N T R O L     --
//---------------------------

//-------------------------------------------------------------------
//-------------------------------------------------------------------
// Start of Debugging config (used if not overridden in template)
// ------------------------------------------------------------------
// ------------------------------------------------------------------
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

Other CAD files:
3Dfiles/YAPPgenerator_v3.3.8.scad
3Dfiles/YAPPgenerator_v3.0.2.scad
3Dfiles/ESP32-DevkitC32D.stl

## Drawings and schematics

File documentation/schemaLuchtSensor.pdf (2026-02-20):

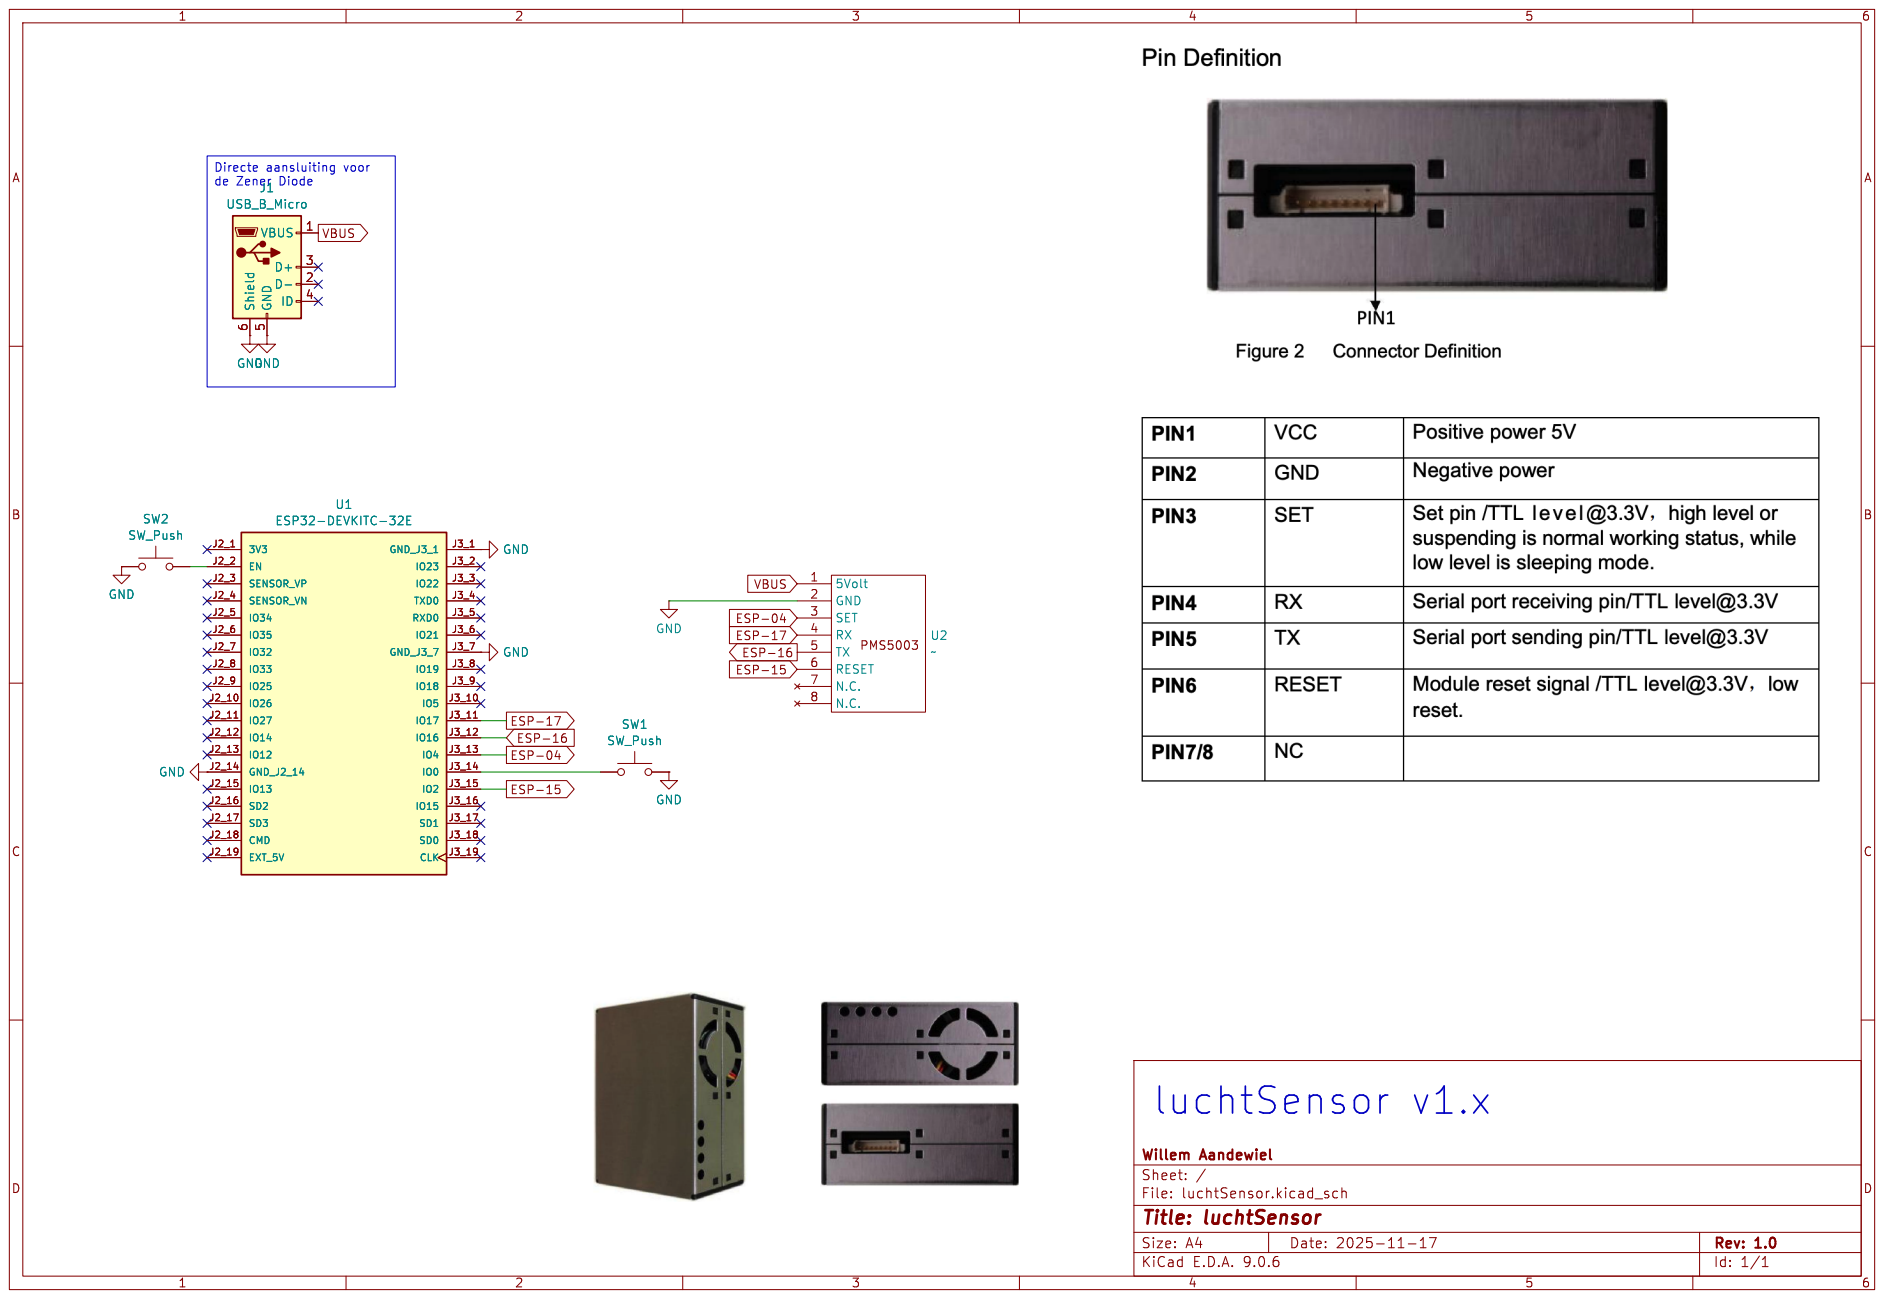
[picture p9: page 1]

Id: 1/1 Title: luchtSensor File: luchtSensor.kicad_sch Sheet: / Willem Aandewiel PMS5003

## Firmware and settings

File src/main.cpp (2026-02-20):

/*** Last Changed: 2026-02-20 - 13:57 ***/
#include <Arduino.h>
#include <string>
#include <cstring>
#include <ArduinoJson.h>
#include "wifiManagerExt.h"
#include "mqttClient.h"
#include "pms5003AirSensor.h"
#include "logger.h"
#include "telnetServer.h"

const char* PROG_VERSION = "v1.0.0";

WifiManagerExt wifiManager;
MqttConfig mqttConfig;
MqttClient* mqttClientInstance = nullptr;
AirSensor airSensor(PIN_PM_RX, PIN_PM_TX);
TelnetServer telnetServer;

SemaphoreHandle_t gConfigMutex = nullptr;

static std::string trimCopy(const std::string& s)
{
  size_t start = 0;
  while (start < s.size() && (s[start] == ' ' || s[start] == '\t'))
  {
    start++;
  }

  if (start == s.size())
  {
    return "";
  }

  size_t end = s.size() - 1;
  while (end > start && (s[end] == ' ' || s[end] == '\t'))
  {
    end--;
  }

  return s.substr(start, end - start + 1);
} //  trimCopy()

static void saveConfigToFile()
{
  if (gConfigMutex != nullptr)
  {
    xSemaphoreTake(gConfigMutex, portMAX_DELAY);
  }

  if (!LittleFS.begin(true))
  {
    if (gConfigMutex != nullptr)
    {
      xSemaphoreGive(gConfigMutex);
    }

    Serial.println("ERROR: Failed to mount LittleFS");
    return;
  }

  JsonDocument doc;
  doc["host"] = mqttConfig.host();
  doc["port"] = mqttConfig.port();
  doc["user"] = mqttConfig.user();
  doc["pass"] = mqttConfig.pass();
  doc["topic"] = mqttConfig.topic();
  doc["interval"] = mqttConfig.measurementIntervalSec();

  File file = LittleFS.open("/config.json", "w");
  if (!file)
  {
    if (gConfigMutex != nullptr)
    {
      xSemaphoreGive(gConfigMutex);
    }

    Serial.println("ERROR: Failed to open config.json for writing");
    return;
  }

  serializeJson(doc, file);
  file.close();

  if (gConfigMutex != nullptr)
  {
    xSemaphoreGive(gConfigMutex);
  }
} //  saveConfigToFile()

static unsigned long getMeasurementIntervalSecSafe()
{
  unsigned long value = 0;

  if (gConfigMutex != nullptr)
  {
    xSemaphoreTake(gConfigMutex, portMAX_DELAY);
  }

  const char* intervalStr = mqttConfig.measurementIntervalSec();
  if (intervalStr != nullptr && intervalStr[0] != '\0')
  {
    value = strtoul(intervalStr, nullptr, 10);
  }

  if (gConfigMutex != nullptr)
  {
    xSemaphoreGive(gConfigMutex);
  }

  return value;
} //  getMeasurementIntervalSecSafe()

void handleSerialCommand(const std::string& command)
{
  if (command == "config")
  {
    if (gConfigMutex != nullptr)
    {
      xSemaphoreTake(gConfigMutex, portMAX_DELAY);
    }

    Serial.println("\nCurrent MQTT Configuration:");
    Serial.printf("  Host: %s\n", mqttConfig.host());
    Serial.printf("  Port: %s\n", mqttConfig.port());
    Serial.printf("  User: %s\n", mqttConfig.user());
    Serial.printf("  Pass: %s\n", mqttConfig.pass());
    Serial.printf("  Topic: %s\n", mqttConfig.topic());
    Serial.printf("  Interval: %s sec\n", mqttConfig.measurementIntervalSec());
    Serial.println();

    if (gConfigMutex != nullptr)
    {
      xSemaphoreGive(gConfigMutex);
    }
  }
  else if (command == "clearauth")
  {
    Serial.println("\nClearing MQTT username and password...");

    if (gConfigMutex != nullptr)
    {
      xSemaphoreTake(gConfigMutex, portMAX_DELAY);
    }

    mqttConfig.setUser("");
    mqttConfig.setPass("");

    if (gConfigMutex != nullptr)
    {
      xSemaphoreGive(gConfigMutex);
    }

    saveConfigToFile();

    Serial.println("MQTT credentials cleared!");
    Serial.println("Type 'restart' to reboot with new settings.\n");
  }
  else if (command == "restart")
  {
    Serial.println("\nRestarting device...\n");
    delay(500);
    ESP.restart();
  }
  else if (command == "help")
  {
    Serial.println("\nAvailable serial commands:");
    Serial.println("  config     - Show current MQTT configuration");
    Serial.println("  clearauth  - Clear MQTT username/password (for anonymous connection)");
    Serial.println("  restart    - Restart the device");
    Serial.println("  help       - Show this help message\n");
  }
  else
  {
    Serial.printf("\nUnknown command: %s\n", command.c_str());
    Serial.println("Type 'help' for available commands.\n");
  }
} //  handleSerialCommand()

//-- RTOS task: Continuously monitor reset button for long press
void taskButtonMonitor(void* pvParameters)
{
  const unsigned long longPressMs = 10000UL;
  bool wasPressed = false;
  unsigned long pressedAt = 0;
  unsigned long lastReportedSecond = 0;

  while (true)
  {
    unsigned long now = millis();
    bool isPressed = (digitalRead(PIN_ERASE_WIFI) == LOW);

    if (isPressed)
    {
      if (!wasPressed)
      {
        wasPressed = true;
        pressedAt = now;
        lastReportedSecond = 0;
        Logger::info("Reset button LOW detected, starting hold timer");
      }

      unsigned long heldMs = now - pressedAt;
      unsigned long heldSeconds = heldMs / 1000UL;

      if (heldSeconds != lastReportedSecond)
      {
        lastReportedSecond = heldSeconds;
        Logger::info("Reset button held for %lu s", heldSeconds);
      }

      if (heldMs >= longPressMs)
      {
        Logger::warn("Reset button held >= 10 seconds, clearing WiFi credentials and restarting");
        wifiManager.reset();
        vTaskDelay(500 / portTICK_PERIOD_MS);
        ESP.restart();
      }
    }
    else if (wasPressed)
    {
      unsigned long heldMs = now - pressedAt;
      Logger::info("Reset button HIGH detected (released) after %lu ms", heldMs);
      wasPressed = false;
      pressedAt = 0;
      lastReportedSecond = 0;
    }

    vTaskDelay(100 / portTICK_PERIOD_MS);
  }
}

//-- RTOS task: Keep MQTT connection alive and process messages
void taskMqttLoop(void* pvParameters)
{
  unsigned long lastReconnectAttempt = 0;
  const unsigned long reconnectInterval = 60000;

  while (true)
  {
    if (mqttClientInstance != nullptr)
    {
      mqttClientInstance->loop();

      //-- Attempt periodic reconnection if disconnected
      if (!mqttClientInstance->isConnected())
      {
        unsigned long now = millis();

        if (now - lastReconnectAttempt >= reconnectInterval)
        {
          lastReconnectAttempt = now;
          Logger::info("Attempting MQTT reconnection...");

          bool reconnected = mqttClientInstance->reconnect(
              wifiManager.getClientId(),
              10,
              []() -> bool
              {
                return false;
              });

          if (reconnected)
          {
            Logger::info("MQTT reconnected successfully");
          }
        }
      }
    }

    vTaskDelay(10 / portTICK_PERIOD_MS);
  }

} //  taskMqttLoop()

//-- RTOS task: Read air sensor periodically and publish data via MQTT
void taskMeasurement(void* pvParameters)
{
  static uint32_t framesOk = 0;
  static uint32_t framesError = 0;
  static uint32_t lastHeartbeat = 0;
  static uint32_t lastStats = 0;
  static uint32_t consecutiveZeroReadings = 0;
  static const uint32_t HEARTBEAT_INTERVAL_MS = 60000;
  static const uint32_t STATS_INTERVAL_MS = 30000;

  //-- Initial warmup on first boot
  Logger::info("taskMeasurement started, warming up sensor...");

  //-- Reset sensor before enabling (required for stable operation)
  airSensor.reset();

#ifndef PM_NEVER_SLEEPS
  //-- Enable sensor only if PM_NEVER_SLEEPS not defined
  digitalWrite(PIN_PM_ENABLE, HIGH);
  vTaskDelay(2000 / portTICK_PERIOD_MS);
#endif

  airSensor.wakeUp();
  Logger::info("Waiting 30 seconds for initial sensor warmup...");
  vTaskDelay(30000 / portTICK_PERIOD_MS);
  Logger::info("Initial warmup complete, starting measurement loop");

  lastHeartbeat = millis();
  lastStats = millis();

  while (true)
  {
    //-- Get measurement interval from config (in seconds)
    unsigned long intervalSec = getMeasurementIntervalSecSafe();

#ifdef PM_NEVER_SLEEPS
    //-- PM sensor is always enabled, no warmup needed, use interval from config
    if (intervalSec > 0)
    {
      Logger::info("Waiting %lu seconds before next measurement", intervalSec);

      //-- Wait with heartbeat and stats during interval
      unsigned long waitStart = millis();
      unsigned long waitEnd = waitStart + (intervalSec * 1000UL);

      while (millis() < waitEnd)
      {
        uint32_t now = millis();

        //-- Heartbeat
        if (now - lastHeartbeat >= HEARTBEAT_INTERVAL_MS)
        {
          lastHeartbeat = now;
          Logger::debug("Heartbeat: millis=%lu, framesOk=%lu, framesError=%lu", now, framesOk, framesError);
        }

        //-- Stats
        if (now - lastStats >= STATS_INTERVAL_MS)
        {
          lastStats = now;
          Logger::debug("Stats: OK frames=%lu, Error frames=%lu, Total=%lu", framesOk, framesError, framesOk + framesError);
        }

        vTaskDelay(100 / portTICK_PERIOD_MS);
      }
    }
#else
    //-- PM sensor can be disabled for power saving
    //-- Minimum interval is 30 seconds when PM_NEVER_SLEEPS is not defined
    if (intervalSec < 30)
    {
      intervalSec = 30;
    }

    //-- Calculate wait time (interval - 30 seconds for warmup)
    unsigned long waitTimeSec = intervalSec - 30;
    if (waitTimeSec > 0)
    {
      Logger::info("Waiting %lu seconds before next measurement", waitTimeSec);

      //-- Wait with heartbeat and stats during interval
      unsigned long waitStart = millis();
      unsigned long waitEnd = waitStart + (waitTimeSec * 1000UL);

      while (millis() < waitEnd)
      {
        uint32_t now = millis();

        //-- Heartbeat
        if (now - lastHeartbeat >= HEARTBEAT_INTERVAL_MS)
        {
          lastHeartbeat = now;
          Logger::debug("Heartbeat: millis=%lu, framesOk=%lu, framesError=%lu", now, framesOk, framesError);
        }

        //-- Stats
        if (now - lastStats >= STATS_INTERVAL_MS)
        {
          lastStats = now;
          Logger::debug("Stats: OK frames=%lu, Error frames=%lu, Total=%lu", framesOk, framesError, framesOk + framesError);
        }

        vTaskDelay(100 / portTICK_PERIOD_MS);
      }
    }

    //-- Reset sensor before enabling for warmup
    airSensor.reset();
    //-- Enable PM sensor for warmup
    Logger::info("Enabling PM sensor for warmup");
    digitalWrite(PIN_PM_ENABLE, HIGH);
    airSensor.wakeUp();

    //-- Wait 30 seconds for sensor warmup
    Logger::info("Waiting 30 seconds for sensor warmup");
    vTaskDelay(30000 / portTICK_PERIOD_MS);
#endif

    //-- Read sensor
    bool valid = airSensor.read();

    if (valid)
    {
      framesOk++;

      float pm1Value = airSensor.pm1();
      float pm25Value = airSensor.pm25();
      float pm10Value = airSensor.pm10();

      //-- Check for consecutive zero readings (sensor malfunction indicator)
      if (pm25Value == 0.0 && pm10Value == 0.0)
      {
        consecutiveZeroReadings++;
        Logger::warn("Zero reading detected (count: %lu)", consecutiveZeroReadings);

        //-- Reset sensor if more than 2 consecutive zero readings
        if (consecutiveZeroReadings > 2)
        {
          Logger::warn("More than 2 consecutive zero readings, resetting esp32");
          ESP.restart();
          consecutiveZeroReadings = 0;
        }
      }
      else
      {
        //-- Reset counter on valid non-zero reading
        consecutiveZeroReadings = 0;
      }

      if (mqttClientInstance != nullptr)
      {
        JsonDocument doc;
        doc["devId"] = wifiManager.getClientId();
        doc["pm1"] = pm1Value;
        doc["pm25"] = pm25Value;
        doc["pm10"] = pm10Value;
        doc["timestamp"] = millis();

        const char* mqttTopic = mqttConfig.topic();
        mqttClientInstance->publishJson(mqttTopic, doc);
        Logger::info("Published %s", mqttTopic);
        Logger::info("  Device ID: %s", wifiManager.getClientId());
        Logger::info("  PM1.0: %.0f µg/m³", pm1Value);
        Logger::info("  PM2.5: %.0f µg/m³", pm25Value);
        Logger::info("  PM10 : %.0f µg/m³", pm10Value);
      }
    }
    else
    {
      framesError++;
      Logger::warn("Failed to read air sensor");
    }

#ifndef PM_NEVER_SLEEPS
    //-- Disable PM sensor for power saving (only if PM_NEVER_SLEEPS not defined)
    Logger::info("Disabling PM sensor");
    airSensor.sleep();
    digitalWrite(PIN_PM_ENABLE, LOW);
#endif
  }

} //  taskMeasurement()

//-- Handle telnet commands specific to luchtsensor
void handleTelnetCommand(const std::string& command)
{
  if (command == "measure")
  {
    telnetServer.println("\r\nReading air sensor...");

    bool valid = airSensor.read();

    if (valid)
    {
      telnetServer.printf("  PM1.0: %.0f µg/m³\r\n", airSensor.pm1());
      telnetServer.printf("  PM2.5: %.0f µg/m³\r\n", airSensor.pm25());
      telnetServer.printf("  PM10 : %.0f µg/m³\r\n", airSensor.pm10());
    }
    else
    {
      telnetServer.println("  Failed to read sensor");
    }

    telnetServer.println("");
  }
  else if (command == "config")
  {
    telnetServer.println("\r\nCurrent MQTT Configuration:");
    telnetServer.printf("  Host: %s\r\n", mqttConfig.host());
    telnetServer.printf("  Port: %s\r\n", mqttConfig.port());
    telnetServer.printf("  User: %s\r\n", mqttConfig.user());
    telnetServer.printf("  Pass: %s\r\n", mqttConfig.pass());
    telnetServer.printf("  Topic: %s\r\n", mqttConfig.topic());
    telnetServer.printf("  Interval: %s sec\r\n", mqttConfig.measurementIntervalSec());
    telnetServer.println("");
  }
  else if (command == "clearauth")
  {
    telnetServer.println("\r\nClearing MQTT username and password...");
    mqttConfig.setUser("");
    mqttConfig.setPass("");

    //-- Save to file
    if (!LittleFS.begin(true))
    {
      telnetServer.println("ERROR: Failed to mount LittleFS");
      return;
    }

    JsonDocument doc;
    doc["host"] = mqttConfig.host();
    doc["port"] = mqttConfig.port();
    doc["user"] = "";
    doc["pass"] = "";
    doc["interval"] = mqttConfig.measurementIntervalSec();

    File file = LittleFS.open("/config.json", "w");
    if (!file)
    {
      telnetServer.println("ERROR: Failed to open config.json for writing");
      return;
    }

    serializeJson(doc, file);
    file.close();

    telnetServer.println("MQTT credentials cleared!");
    telnetServer.println("Type 'restart' to reboot with new settings.");
    telnetServer.println("");
  }
  else if (command == "restart")
  {
    telnetServer.println("\r\nRestarting device...\r\n");
    delay(500);
    ESP.restart();
  }
  else
  {
    telnetServer.printf("\r\nUnknown command: %s\r\n", command.c_str());
    telnetServer.println("Available luchtsensor commands:");
    telnetServer.println("  measure    - Read current air quality");
    telnetServer.println("  config     - Show current MQTT configuration");
    telnetServer.println("  clearauth  - Clear MQTT username/password (for anonymous connection)");
    telnetServer.println("  restart    - Restart the device");
    telnetServer.println("");
  }
}

//-- RTOS task: Handle telnet server connections and data
void taskTelnetServer(void* pvParameters)
{
  while (true)
  {
    telnetServer.loop();
    vTaskDelay(50 / portTICK_PERIOD_MS);
  }

} //  taskTelnetServer()

void taskSerialConsole(void* pvParameters)
{
  (void)pvParameters;

  std::string command;
  command.reserve(128);

  while (true)
  {
    while (Serial.available() > 0)
    {
      char c = (char)Serial.read();

      if (c == '\n')
      {
        command = trimCopy(command);

        if (!command.empty())
        {
          handleSerialCommand(command);
        }

        command.clear();
      }
      else if (c != '\r')
      {
        command.push_back(c);

        if (command.size() > 256)
        {
          command.clear();
          Serial.println("\nERROR: command too long\n");
        }
      }
    }

    vTaskDelay(20 / portTICK_PERIOD_MS);
  }
} //  taskSerialConsole()

//-- Setup: Initialize hardware, WiFi, MQTT and start RTOS tasks
void setup()
{
  Serial.begin(115200);
  Logger::info("Booting Luchtsensor...");

  pinMode(PIN_ERASE_WIFI, INPUT_PULLUP);
  pinMode(PIN_PM_ENABLE, OUTPUT);
#ifdef PM_NEVER_SLEEPS
  //-- Keep PM sensor always enabled
  digitalWrite(PIN_PM_ENABLE, HIGH);
#else
  digitalWrite(PIN_PM_ENABLE, LOW);
#endif

  gConfigMutex = xSemaphoreCreateMutex();
  if (gConfigMutex == nullptr)
  {
    Logger::error("Failed to create config mutex");
  }

  //-- Check if config.json exists and load it
  bool configFileExists = wifiManager.configExists();

  //-- Check if host is empty or null (even if config file exists)
  bool hostIsEmpty = false;
  if (configFileExists)
  {
    //-- Load config to check host value
    if (!LittleFS.begin(true))
    {
      Logger::error("LittleFS mount failed");
    }

    File file = LittleFS.open("/config.json", "r");
    if (file)
    {
      JsonDocument doc;
      DeserializationError error = deserializeJson(doc, file);
      file.close();

      if (!error)
      {
        const char* host = doc["host"];
        if (host == nullptr || strlen(host) == 0)
        {
          Logger::info("Host in config.json is empty or null");
          hostIsEmpty = true;
        }
      }
    }
  }

  //-- Start captive portal if no config exists or host is empty
  if (!configFileExists || hostIsEmpty)
  {
    if (!configFileExists)
    {
      Logger::info("Starting captive portal (no config file found)");
    }
    else if (hostIsEmpty)
    {
      Logger::info("Starting captive portal (host is empty/null)");
    }

    wifiManager.startPortal(mqttConfig);
    Logger::info("Captive portal completed, restarting...");
    delay(1000);
    ESP.restart();
  }

  //-- Normal WiFi/MQTT connection
  bool wifiOk = wifiManager.begin(mqttConfig);
  if (!wifiOk)
  {
    Logger::error("Failed to initialize WiFi/MQTT config");
  }

  mqttClientInstance = new MqttClient(mqttConfig);

  //-- Connect to MQTT with retry limit and button abort check
  bool mqttConnected = mqttClientInstance->connect(
      wifiManager.getClientId(),
      10,
      []() -> bool
      {
        return digitalRead(PIN_ERASE_WIFI) == LOW;
      });

  if (!mqttConnected)
  {
    Logger::warn("Starting without MQTT connection, will retry periodically");
  }

  airSensor.begin();

  //-- Start telnet server and link to logger
  telnetServer.begin();
  Logger::setTelnetServer(&telnetServer);
  telnetServer.setCommandCallback(handleTelnetCommand);
  Logger::info("Telnet server started on port 23");

  // xTaskCreate(
  xTaskCreatePinnedToCore(
      taskButtonMonitor,
      "ButtonMonitor",
      4096,
      nullptr,
      0,
      nullptr,
      0);

  // xTaskCreate(
  xTaskCreatePinnedToCore(
      taskMqttLoop,
      "MqttLoop",
      4096,
      nullptr,
      1,
      nullptr,
      0);

  xTaskCreatePinnedToCore(
      taskMeasurement,
      "measure",
      4096,
      NULL,
      4,
      NULL,
      1 // run ONLY on Core 1
  );

  // xTaskCreate(
  xTaskCreatePinnedToCore(
      taskTelnetServer,
      "TelnetServer",
      4096,
      nullptr,
      1,
      nullptr,
      0);

  xTaskCreatePinnedToCore(
      taskSerialConsole,
      "SerialConsole",
      4096,
      nullptr,
      1,
      nullptr,
      0);

  Logger::info("Luchtsensor device started with RTOS tasks");

} //  setup()

//-- Main loop: Handle serial commands
void loop()
{
  vTaskDelay(1000 / portTICK_PERIOD_MS);

} //  loop()

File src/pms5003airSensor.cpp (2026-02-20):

/*** Last Changed: 2026-02-20 - 13:57 ***/
#include "pms5003AirSensor.h"
#include "logger.h"

//-- Constructor: Initialize air sensor with RX/TX pins for PM sensor communication
AirSensor::AirSensor(uint8_t rxPin, uint8_t txPin)
    : rxPin(rxPin),
      txPin(txPin),
      pmsSerial(2),
      pms(pmsSerial)
{
}

//-- Initialize the PM sensor UART and library
void AirSensor::begin()
{
  //-- Setup RESET pin if defined (otherwise sensor has internal pull-up)
  if (PIN_PM_RESET >= 0)
  {
    pinMode(PIN_PM_RESET, OUTPUT);
    digitalWrite(PIN_PM_RESET, HIGH);
    Logger::info("AirSensor RESET pin %d configured (HIGH)", PIN_PM_RESET);
  }

  pmsSerial.begin(9600, SERIAL_8N1, rxPin, txPin);
  Logger::info("AirSensor initialized on RX=%d, TX=%d", rxPin, txPin);
}

//-- Reset the PM sensor
void AirSensor::reset()
{
  if (PIN_PM_RESET >= 0)
  {
    digitalWrite(PIN_PM_RESET, LOW);
    vTaskDelay(250 / portTICK_PERIOD_MS);
    digitalWrite(PIN_PM_RESET, HIGH);
    Logger::info("AirSensor reset");
  }
  else
  {
    Logger::warn("AirSensor reset skipped (PIN_PM_RESET not defined)");
  }
}
//-- Wake up the PM sensor from sleep mode
void AirSensor::wakeUp()
{
  pms.wakeUp();
  Logger::info("AirSensor woken up");
}

//-- Put the PM sensor into sleep mode for power saving
void AirSensor::sleep()
{
  pms.sleep();
  Logger::info("AirSensor put to sleep");
}

//-- Read PM values from sensor using PMS library (blocking with high-priority polling)
bool AirSensor::read()
{
  const unsigned long timeout = 5000;
  unsigned long startTime = millis();

  //-- Poll sensor until data received or timeout
  //-- High task priority ensures this gets sufficient CPU time
  while (millis() - startTime < timeout)
  {
    if (pms.read(pmsData))
    {
      Logger::info("AirSensor: PM1.0=%u, PM2.5=%u, PM10=%u", pmsData.PM_AE_UG_2_5, pmsData.PM_AE_UG_10_0);
      return true;
    }

    //-- Brief RTOS-friendly delay to yield to other tasks if needed
    vTaskDelay(pdMS_TO_TICKS(50));
  }

  Logger::warn("AirSensor: read() timeout after %lu ms", timeout);
  return false;
}

//-- Get last read PM1.0 value (atmospheric environment, µg/m³)
float AirSensor::pm1() const
{
  return (float)pmsData.PM_AE_UG_1_0;
}

//-- Get last read PM2.5 value (atmospheric environment, µg/m³)
float AirSensor::pm25() const
{
  return (float)pmsData.PM_AE_UG_2_5;
}

//-- Get last read PM10 value (atmospheric environment, µg/m³)
float AirSensor::pm10() const
{
  return (float)pmsData.PM_AE_UG_10_0;
}

//-- Get complete last reading data structure
PMS::DATA AirSensor::getLastData() const
{
  return pmsData;
}

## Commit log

2026-02-20 - Enhance reset button monitor to continuously check for 10-second hold instead of only monitoring first 60 seconds after boot - Add progress logging during button hold with per-second updates - Rena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
2026-02-20 Revise README for sensor and MQTT updates
    Updated README to reflect changes in sensor measurements, MQTT topics, and build environment.
2026-02-22 chore: add projects directory to gitignore
    Added the 'projects' directory to .gitignore to prevent local project files from being tracked in version control.
    [YAPP_Hooktest_v30.scad, YAPP_Template_v3.scad, luchtSensor.kicad_pcb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]
